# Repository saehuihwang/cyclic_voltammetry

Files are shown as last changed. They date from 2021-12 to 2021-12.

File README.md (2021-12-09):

# cyclic_voltammetry

Here, a functional cyclic voltametry (CV) device is presented. A three-electrode electrochemical cell is composed of a working electrode, a reference electrode, and a counter electrode. The working principle of cyclic voltammetry is that a range of voltages is applied to a working electrode and the resulting current is measured. This current can tell us information about an electrochemical redox reaction. Oxidation occurs at the working electrode, reduction occurs at the counter electrode.  

Following conventional CV design, a triangle wave is applied at the working electrode and current flowing between the working and counter electrode is measured. By plotting the current vs applied potential, a traditional "duck plot" can be obtained. 

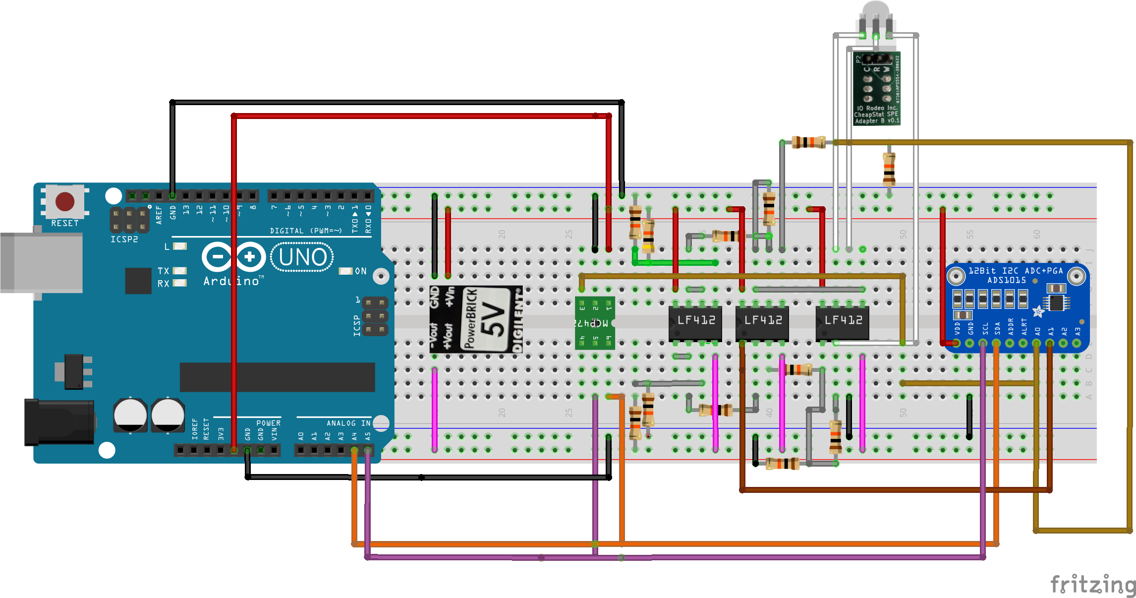
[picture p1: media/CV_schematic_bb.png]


### Duck plots
The Randles-Sevcik equation can be used to extract useful information about the electrochemical reaction. Detailed analysis can be found in the project report. 

Below are some examples of duck plots with varying parameters such as scan rate and concentration. 

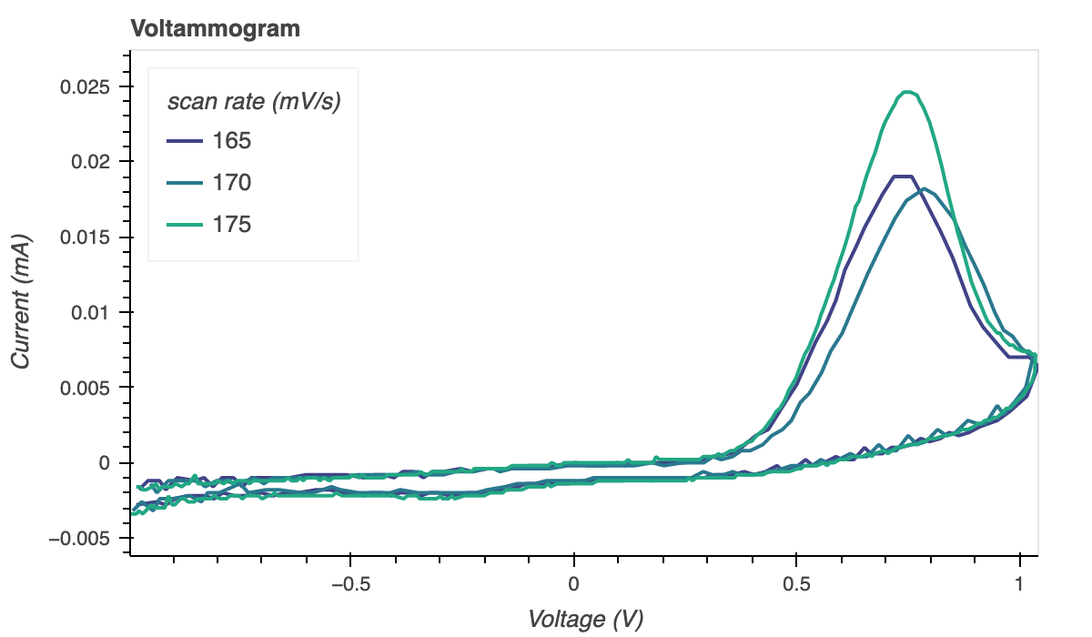
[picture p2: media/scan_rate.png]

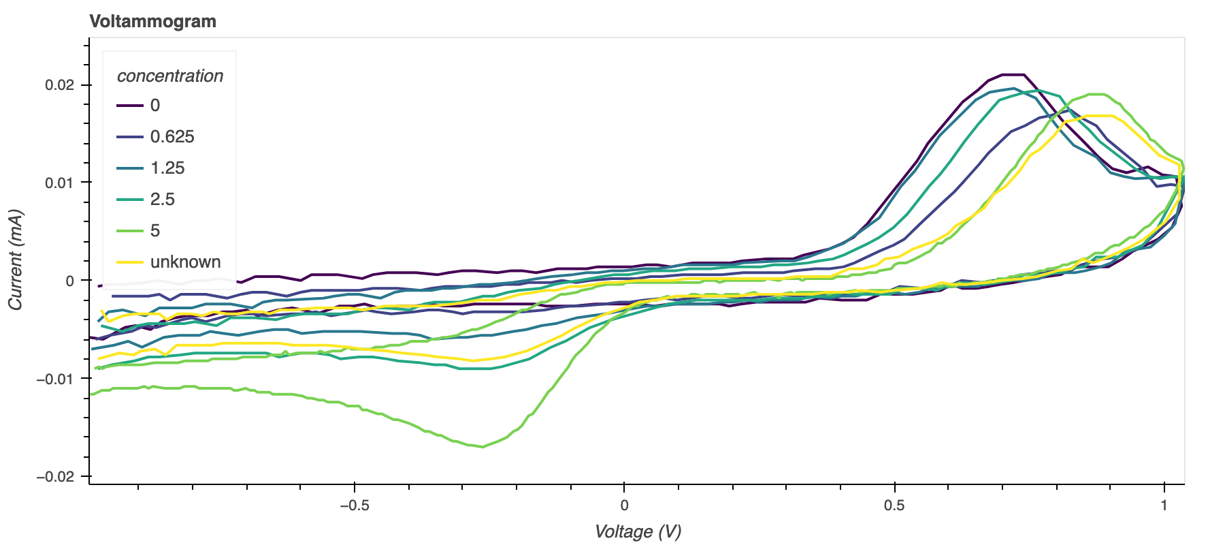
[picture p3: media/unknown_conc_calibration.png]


### App & User Interface 
To run the app, run 

  `bokeh serve --show cv_app.py`
  
On the command line.   
The following user interface will show, displaying the scan rate adjusting sliders and a plotting interface 
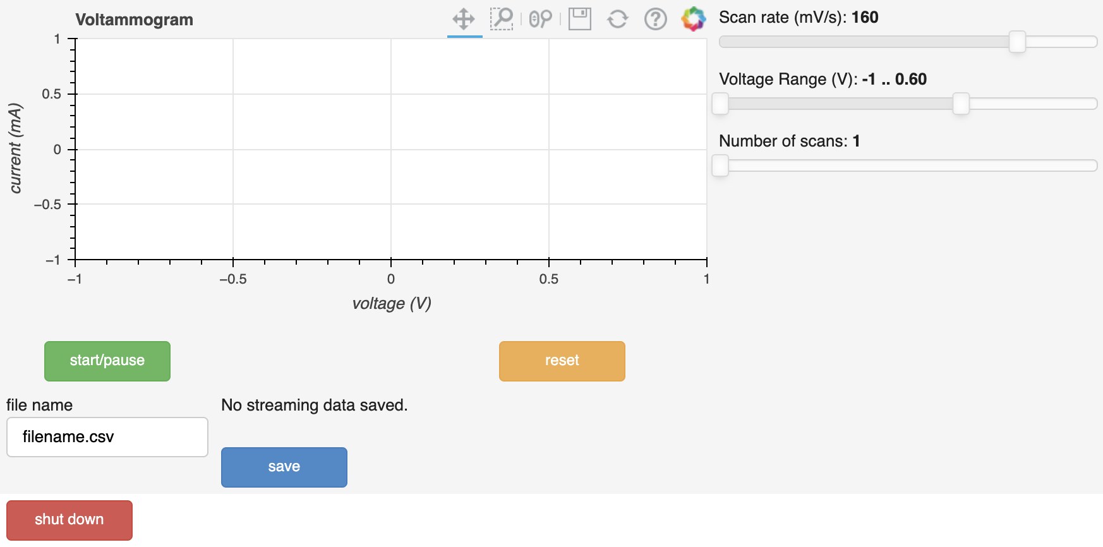
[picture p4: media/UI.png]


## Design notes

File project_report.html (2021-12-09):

## Section 1: Overview¶

In this report, a functional cyclic voltametry (CV) device is presented. A three-electrode electrochemical cell is composed of a working electrode, a reference electrode, and a counter electrode. The working principle of cyclic voltammetry is that a range of voltages is applied to a working electrode and the resulting current is measured. This current can tell us information about an electrochemical redox reaction. Oxidation occurs at the working electrode, reduction occurs at the counter electrode.

## Section 2: Design¶

Following conventional CV design, a triangle wave is applied at the working electrode and current flowing between the working and counter electrode is measured. By plotting the current vs applied potential, a traditional "duck plot" can be obtained.

The presented design is characterized by its easy-to-use user interface and its clean output trace. Significant attention has been paid to make the schematic and breadboard clean and easily readable. Furthermore, when saving the result to a .csv file, the scanning parameters (scan rate, scan range, # scan) are also saved to the file.

### Schematic¶

LF412 Dual Op-Amps were chosen for its low power requirement and high input impedance.

- Two reference voltages must be created at 1V and -2.5V. This is achieved using a simple resistive voltage divider and a buffer.
- Two subtractors are in place. All resistors in the subtractor is chosen to be the same value, $10k\Omega$. Therefore, the output of the subtractor is as follows: $$V_{out} = V_2 - V_1$$ where $V_2$ is the voltage connected to the positive terminal, and $V_1$ is the voltage connected to the negative terminal. When -2.5V is presented at $V_1$, this circuit behaves like an adder (+2.5V).
- The DAC can only output positive voltages ranging from 0Vto 5V. Therefore, we subtract 1V from the resulting signal in order to allow for a scanning range of -1V to 4V. Conventional CV applied potentials often lie within this range.
- The ADC can only read positive voltages, but we know that the measured TIA voltage could be negative. Therefore, the output of the TIA is shifted up by 2.5V. to provide for maximum reading range. Upon testing, this value has shown to be appropriate, as clipping was never observed. Upon reading the shifted output of the TIA, 2.5V is subtracted digitally to recover the original signal. The ADC's inability to read negative voltages also meant that the applied potential was measured before shifting it down by 1V. The signal was shifted down by 1V digitally to recover the actual applied potential value. In summary, the ADC was used to read two voltages: the DAC output and the TIA output.
- The current between the working and counter electrode is measured using a TIA. A simple resistive feedback op amp is used for this. A resistor value of $1k\Omega$ was specifically chosen for the feedback resistor, for a convenient conversion between measured volts to mA, according to $I = V/R$. Upon testing, no significant noise issues were present, so a capacitor has been omitted but it could be added at later design iterations if noise becomes an issue.

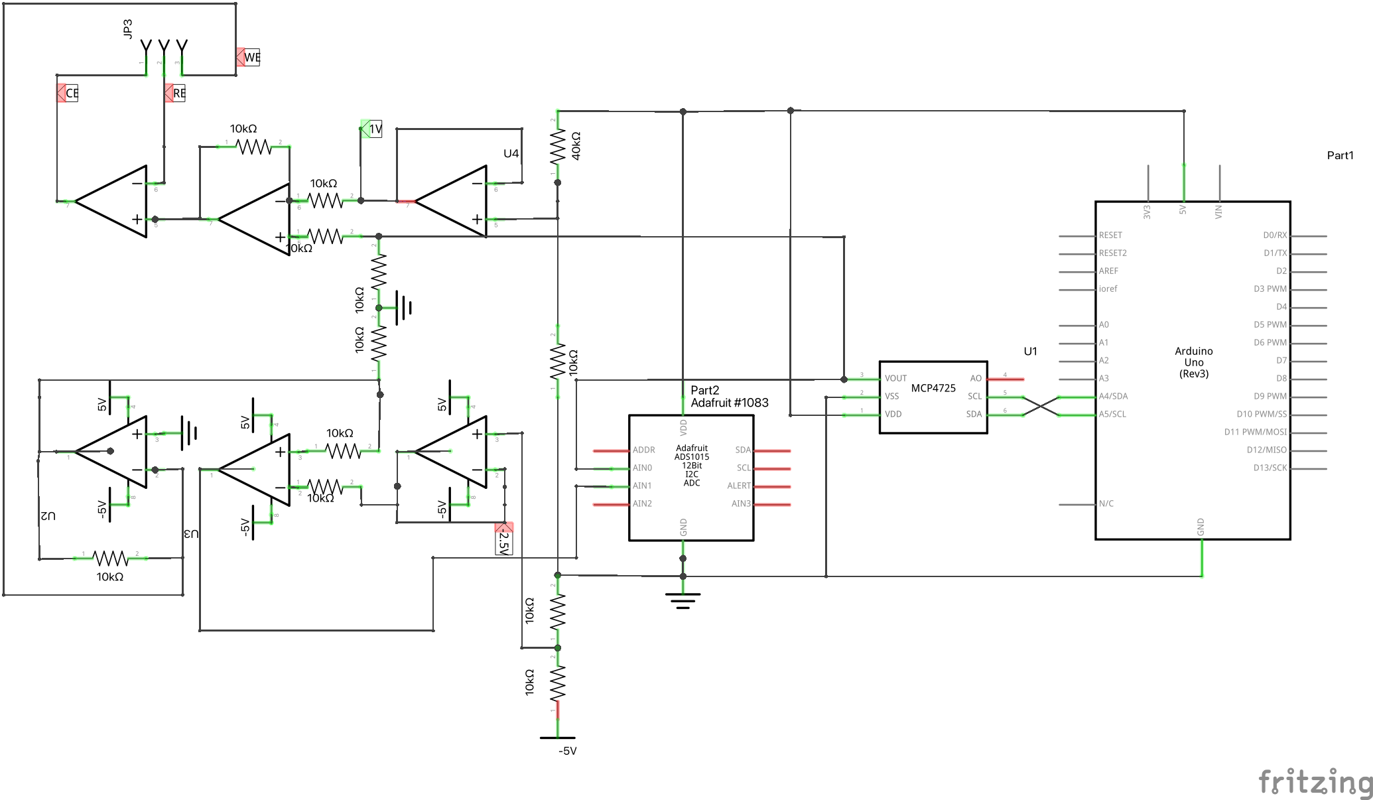
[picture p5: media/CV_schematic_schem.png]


### Breadboard Wiring¶



### Block Diagram¶

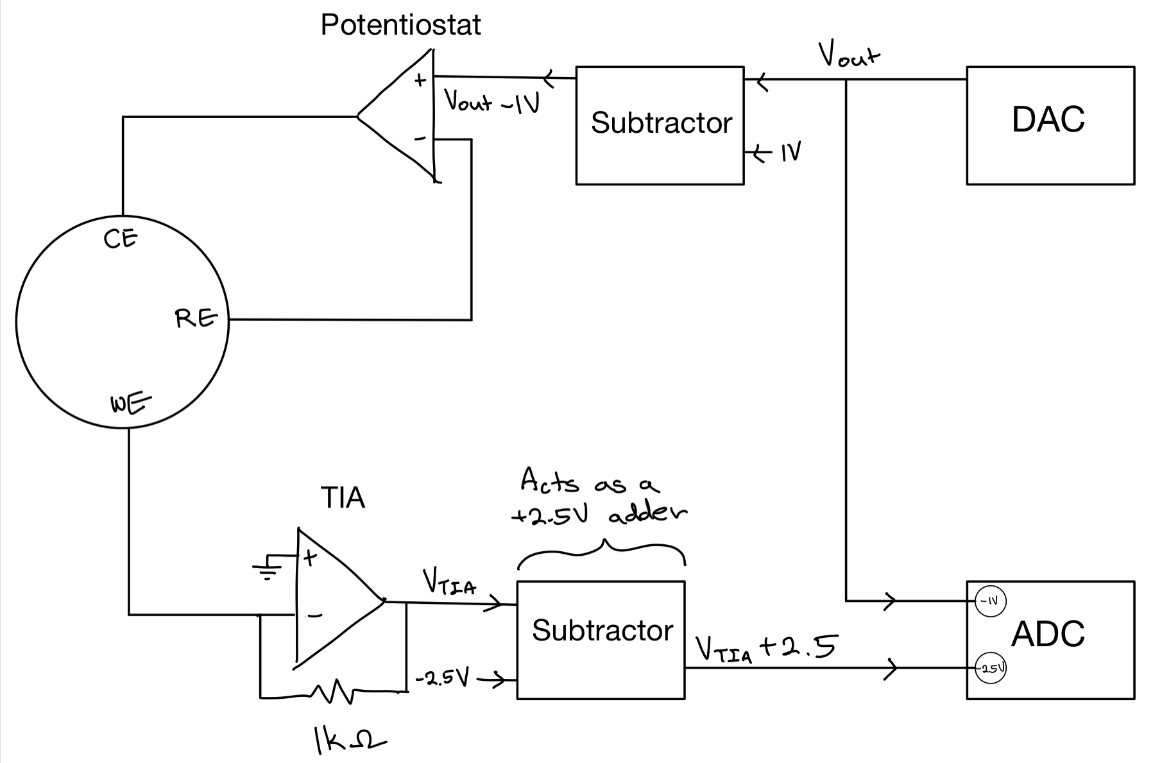
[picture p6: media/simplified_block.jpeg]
This simplified block diagram shows how signals were shifted up/down in analog and in digital domains. 

### User Interface¶

- The user interface has three sliders: a scanrate selector, a voltage range selector, and a scan number selector. A range slider is implemented for the voltage range slider so that the user is able to easily adjust the range using the two ends of the slider. The sliders are disabled during the course of a voltage scan. They are enabled once the voltage scanning is over or when it is reset.
- The start/pause button starts and pauses the voltage scan. When the user pauses the scan, the DAC holds the voltage. The user can press the button again to resume the scan.
- The reset button clears the plot and the data. The voltage scan is reset to 0V.
- The save button can be pressed while there is no active scanning. (i.e, can save when paused). The user is able to specify a file name. Any files with the same file name will be overwritten.
- The shut down button can be pressed to stop streaming and shut down the app.



### Software¶

#### Arduino¶

- There are several command bytes to control the arduino. Namely,
  - HANDSHAKE
  - START_PAUSE
  - STOP
  - READ_SWEEPTIME
  - READ_VLOW
  - READ_VHIGH
  - READ_NUM_SCAN
- The triangle wave generation is done ditigally . The main drawback of this approach is suboptimal voltage resolution. However, this method is much easier to debug and for prototyping purposes, it will suffice.
- The user is able to set the scan range anywhere from -1 to 4V. Since the DAC cannot output negative voltages, 1V is added to any user specified value and the corresponding DAC voltage is outputted, with the assumption that there is an op-amp subtractor that takes care of the subtraction in the analog domain.
- In other words, when the user specifies the desired voltage range as $V_{Low}$ and $V_{High}$, the DAC translation for a desired voltages is computed as follows $$dac_{vLow} = \frac{V_{Low} + 1}{5} \cdot 4095 $$ $$dac_{vHigh} = \frac{V_{High} + 1}{5} \cdot 4095 $$ One downside of this method is that the voltage resolution is limited by 1.2mV. Even when the desired amplitude is smaller, the voltage resolution stays the same. We are not taking full advantage of the 12 bit DAC when the desired amplitude is less than 5V.
- The MCP4725 $V_{out}$ ranges from $V_{SS}$ (0V) to $V_{DD}$ (5V). There is a counter that counts up (for rising edge) or down (for falling edge) from the bit translation of $V_{low}$ (for rising edge) or $V_{high}$ (for falling edge).
- The scan rate is implemented as follows
  - For convenience and readability, "sweeptime" is used in the arduino code rather than the conventional "scan rate". The sweeptime is another word for "period" of the triangle wave. The conversion is quite simple $${sweeptime} = (({V_{high} - V_{low}}) \div {scanrate}) \times 2 $$ and is done on the python side
  - There is a .delay() of $\frac{sweeptime}{2} \div \text{bit translation of amplitude}$ in between DAC outputs. This is because the bit translation of amplitude represents the number of discrete voltage values that needs to be outputted during the rising/falling edge. This method relies upon the assumption that the ADC reading and DAC outputting operation takes negligible time. Therefore the actual sweeptime may be slightly more than the user specified value. This also has the downside that the sweeprate is limited by the arduino baud rate. The minimum sweep rate was measured to be around 10 seconds. Luckily for us, conventional sweeptimes are longer than this. The last drawback is the reduced time resolution. Since the arduino is under delay(), the ADC is unable to read anything during this time. This results in a reduced number of data points.
- After each voltage output, the code checks if there were any START_PAUSE command or STOP command. This allows us to hold or reset the voltage during a sweep.
- When the sweep is complete, the message "DONE SWEEPING" is outputted to serial so that the python side can immediately know when the sweeping has concluded.
- When no sweeping is taking place, the DAC outputs the voltage of 1V which is shifted down to 0V by the subtractor (OFF state). #### Python
- Since the 1V subtractor and the 2.5V adder is implemented in analog to output the correct voltage, we must subtract 1V and subtract 2.5V digitally to compensate (see block diagram).
- When saving to a .csv file, the user specified scanning parameters are saved at the top of the csv file so that when doing analysis, the user can easily recover the scan parameters that were used.

## Section 3: Instructions for Use¶

1. Rinse the DropSens SPCE under running water and let it air dry before plugging into the adaptor.
2. Use a clean pipette to drop 1 or 2 drops of analyte to the DropSense SPCE such that the three electrodes are fully covered. This should be approximately 50$\mu L$ of analyte. Be careful not to touch the electrode surface with the pipette tip.
3. Make the sure electrode is flat against the table.
4. Run the app from the terminal bokeh serve --show cv_app.py
5. Adjust scanning parameters by dragging the sliders
  - scan rate (mV/s)
  - voltage range (V)
  - number of scans
6. Click start/pause
7. To pause during a scan, click start/pause. To stop the scan, click reset. During a scan, the scanning parameters cannot be adjusted
8. To save a trace, specify a file name and click save. One can save when the scanning is paused or when the scanning has been completed.
9. When finished, gently rinse under running water and let it air dry before storing away from direct sunlight. The app can be closed by clicking shut down.

## Section 4: Demonstration and assessment¶

#### Voltage Scan verification¶

An oscilloscope was used to verify that the triangle wave output was as expected. 
Channel 1 is the DAC output and Channel 2 is the subtractor output. A shift of 1V is measured, as expected. A sweeptime of 1.4 seconds was specified to the arduino and the measured period is 1.48 seconds, as expected. No distortions are observed.

#### Demonstration video.¶

A video footage of the functioning device is included in the media/ folder.

## Section 5: Analysis of data¶

In [1]:

import pandas as pd
import scipy.signal
import numpy as np
import os
import holoviews as hv
import bokeh.plotting
import bokeh.io

bokeh.io.output_notebook()
hv.extension("bokeh")
%load_ext blackcellmagic

(https://bokeh.org) Loading BokehJS ...

#### Helper Functions¶

In [7]:

def tidy_cv_df(filename, conc=None):
    """ turns a raw .csv file name into a tidy dataframe """
    df = pd.read_csv(filename)
    df["scan rate (mV/s)"] = int(df["0"][0])
    df["scan low (V)"] = df["0"][1]
    df["scan high (V)"] = df["0"][2]
    df["num scan"] = df["0"][3]
    df["Voltage (V)"] = df["Voltage (V)"] - 1
    df["Current (mA)"] = (df["Current (mA)"] - 2.5)/10
    if conc is not None:
        df["concentration"] = conc
    return df[4:].reset_index(drop=True)

def cap_curr_fit(df, v_oxidation):
    """returns the line of best fit for the capacitive current"""
    x_range = df["Voltage (V)"]
    data = df.loc[df["Voltage (V)"] < v_oxidation]
    mid_time = np.median(df["time (ms)"])
    x = data.loc[data["time (ms)"] < mid_time]["Voltage (V)"]
    y = data.loc[data["time (ms)"] < mid_time]["Current (mA)"]
    line_fit = np.poly1d(np.polyfit(x, y, 1))

    return x_range, line_fit(x_range)

def extract_ipa(df, v_oxidation=0.2):
    """ calculates the peak anodic current by maximizing the distance 
    between the capacitive current and the measured current """
    y = df["Current (mA)"]
    y_line = cap_curr_fit(df, v_oxidation)[1]

    ind_max = np.argmax((y - y_line) ** 2)
    # peak anodic current
    ipa = y[ind_max] - y_line[ind_max]
    return (ind_max, ipa)

Now that we have some helper functions, let's look at some duck plots!

#### Effects of the number of scans¶

We observe that the peak anodic potential decreases to a negligible amount after the first scan. This makes sense because we know that the reaction of Ascorbic acid is irreversible (further discussion below). After the first scan the surface of the electrode is oxidized and no further oxidation occurs. This is why from now on, we will simply conduct $n=1$ scans.

#### Effect of scan rate on $i_{pa}$¶

In [8]:

data_path = './data/diffusion_coeff_data/'
rates = [175, 170, 165]
dfs = [tidy_cv_df(os.path.join(data_path, f"0.625mM_{rate}.csv")) for rate in rates]

df = pd.concat(dfs)

p = (
    hv.Curve(data=df, kdims="Voltage (V)", vdims=["Current (mA)", "scan rate (mV/s)"])
    .groupby("scan rate (mV/s)")
    .opts(
        color=hv.Cycle(list(bokeh.palettes.Viridis6[1:-1])),
        width=600,
        height=350,
        title="Voltammogram",
    )
    .overlay().opts(legend_position='top_left')
)

p = hv.render(p)
bokeh.io.show(p)

We observe that there is negligible cathodic peak current. This allows us to deduce that the reaction of vitamin C is irreversible. This is in line with our understanding of vitamin C as an antioxidant, as it is a reducing agent.

Visually, we can see that as scan rate increases, so does the peak anodic current ($i_{pa}$). We have written up a helper function to extract this value. To demonstrate that the extraction of $i_{pa}$ works as expected, we will visualize one of the curves.

In [9]:

df_170 = df.loc[df["scan rate (mV/s)"] == 170]

p = hv.render(
    hv.Curve(data=df_170, kdims="Voltage (V)", vdims=["Current (mA)"]).opts(
        width=600,
        height=350,
        title="Voltammogram",
    )
)

ipa_ind, ipa = extract_ipa(df_170)
cap_curr_x, cap_curr_y = cap_curr_fit(df_170, 0.2)

# Plot
p.line(x=cap_curr_x, y=cap_curr_y, line_dash='dashed', color='black', width=3)
p.circle(
    x=df_170["Voltage (V)"][ipa_ind], y=df_170["Current (mA)"][ipa_ind], color="red", size=5
)
p.segment(
    x0=cap_curr_x[ipa_ind],
    y0=cap_curr_y[ipa_ind],
    x1=df_170["Voltage (V)"][ipa_ind],
    y1=df_170["Current (mA)"][ipa_ind],
    color="pink", width=5
)
bokeh.plotting.show(p)

The pink line segment represents the calculated $i_{pa}$. $i_{pa}$ is found by maximizing the distance between the capacitive current and the trace. Accurately finding the capacitive current requires a careful consideration of the theory and doing generative modeling. For simplicity, we have simply done a linear fit of the region below 0.2V, as that is where the plot seems to behave linearly. Now that we've verified our helper functions, we can use this to calculate the diffusion coefficient.

#### Extracting the diffusion coefficient¶

Multiple CV experiments for various scan rates have been performed. Then, a least squares regression of $i_{pa}$ vs $v$ according to the Randles-Sevcik equation, $$i_{pa} = 0.4463nFAc\sqrt{\frac{nFvD}{RT}}$$ was performed.

parameter | Description | Value
n | number of electrons transferred | $$1$$
A | electrode area | $$\pi \cdot (0.2)^2 (cm^2)$$
T | temperature | $$293 (K)$$
v | scan rate | varies $(V/s)$
F | Faraday Constant | $$96500 (C/mol)$$
D | Diffusion Coefficient | want to find $ (cm^2/s)$
R | Gas Constant | $$8.31 (J/(K mol))$$
C | concentration | $$6.25 \cdot 10^{-7} (mol/cm^3)$$

We will let $n=1$, as suggested $\href{https://en.wikipedia.org/wiki/Randles%E2%80%93Sevcik_equation}{here} $

In [10]:

# create a dataframe of peak anodic current wrt. scan rate
dfs = []
for rate in df["scan rate (mV/s)"].unique():
    ipa_ind, ipa = extract_ipa(df.loc[df["scan rate (mV/s)"] == rate])
    dfs.append(pd.DataFrame({"scan rate (mV/s)": rate, "ipa (mA)": ipa}, index=[0]))
ipas = pd.concat(dfs).reset_index(drop=True)
ipas["scan rate (V/s)"] = ipas["scan rate (mV/s)"] / 1000
ipas["ipa (A)"] = ipas["ipa (mA)"] / 1000

def randles(v, D):
    """ The Randles-Sevcik equation used in `scipy.optimize.curve_fit` """
    n = 1
    r = 0.2  # cm
    A = np.pi * r ** 2 # cm^2
    R = 8.31 # J/(K mol)
    F = 96500 # in C / mol
    T = 293  # room temperature
    c = 0.625 / 1000 * 1000 / (100 ** 3) # mol / cm^3
    return (
        0.4463 * n * F * A * c * (n * F * v * D / (R * T)) ** (1 / 2)
    )

popt, pcov = scipy.optimize.curve_fit(randles, ipas["scan rate (V/s)"], ipas["ipa (A)"])

# plot
p = bokeh.plotting.figure(
    width=400,
    height=400,
    x_axis_label="scan rate (mV/s)",
    y_axis_label="peak anodic current (mA)",
)
p.circle(x=ipas["scan rate (mV/s)"], y=ipas["ipa (mA)"])
v_range = np.linspace(0.1, 0.2, 1000)
p.line(x=1000*v_range, y=randles(v_range, *popt)*1000)
bokeh.io.show(p)

In [11]:

print(f"Calculated Diffusion Coefficient in cm^2/s: {popt}")

Calculated Diffusion Coefficient in cm^2/s: [5.06907637e-06]

Literature ($\href{https://pubs.rsc.org/en/content/articlelanding/2020/NJ/D0NJ02175J}{Yomthiangthae, 2020}$) suggests that the diffusiuon coefficient of vitamin C is $5.32 \cdot 10^{-6} {cm}^2 s^{-1}$. Our estimated value for the diffusion coefficient is similar to this value by an order of magnitude!

One important thing to note is that the measured current has been divided by 10 in tidy_cv_df() because our measured current using the arduino was off by a factor of 10 from the measured current using a multimeter. It is unclear why this happened, but this behavior has also been observed by other students. After intensive debugging, the source of this 10x factor was not found. It may be that the SPCE has an internal resistance that we neglected to account for. For analytical purposes, we divide the arduino current readout by 10 so that it matches the current readout from the multimeter.

Furthermore, of course, ideally, we would have more datapoints to help us be more confident in our diffusion coefficient fit. Due to time constraints, only three data points have been acquired.

### Calculating an unknown concentration¶

Since we have found that our diffusion coefficient calculation is likely flawed, we can use a more direct approach in calculating the concentration of an unknown solution.

In [12]:

data_path = './data/calibration_data/'

concentrations = [0, 0.625, 1.25, 2.5, 5, 'unknown']
dfs = [tidy_cv_df(os.path.join(data_path, f"calibrate_{conc}mM.csv"), conc) for conc in concentrations]

df = pd.concat(dfs)

p = (
    hv.Curve(data=df, kdims="Voltage (V)", vdims=["Current (mA)", "concentration"])
    .groupby("concentration")
    .opts(
        color=hv.Cycle(list(bokeh.palettes.Viridis6)),
        width=900,
        height=400,
        title="Voltammogram",
    )
    .overlay().opts(legend_position='top_left')
)

p = hv.render(p)
bokeh.io.show(p)

We again extract $i_{pa}$ and store it in a dataframe.

In [13]:

dfs=[]
for conc in df["concentration"].unique():
    ipa_ind, ipa = extract_ipa(df.loc[df["concentration"]==conc], v_oxidation=-0.5)
    dfs.append(pd.DataFrame({"concentration":conc, "ipa": ipa}, index=[0]))
    
ipas = pd.concat(dfs).reset_index(drop=True)
ipas

Out[13]:

| concentration | ipa
0 | 0 | 0.017524
1 | 0.625 | 0.016405
2 | 1.25 | 0.015526
3 | 2.5 | 0.018170
4 | 5 | 0.020856
5 | unknown | 0.017032

From the Randles-Sevcik equation, $$i_{pa} = 0.4463nFAc\sqrt{\frac{nFvD}{RT}}$$ we know that $i_{pa}$ has a linear relationship with $c$, the concentration. We will conduct a linear fit of our data to find the unknown concentration.

In [14]:

known_conc = ipas.loc[ipas["concentration"] != "unknown"].astype("float")
p = bokeh.plotting.figure(width = 400, height=400, x_axis_label="concentration", y_axis_label="peak anodic current (mA)")
p.circle(x=known_conc["concentration"], y=known_conc["ipa"])
z = np.polyfit(known_conc["concentration"], known_conc["ipa"], 1)
best_fit_line = np.poly1d(z)
conc_range = np.linspace(0,5,100)
p.line(x=conc_range, y=best_fit_line(conc_range), line_dash='dashed', color='black')

unknown_ipa = ipas.loc[ipas["concentration"] == 'unknown']['ipa'].values
unknown_conc = ( unknown_ipa - z[1])/z[0]
p.circle(x=unknown_conc, y=unknown_ipa, color='red')
bokeh.io.show(p)

In [15]:

print(f"The unknown concentration is approximately: {unknown_conc} mM")

The unknown concentration is approximately: [1.10359977] mM

## Section 6: Suggestions for the next design phase¶

1. Understand the behavior of the screen printed carbon electrode better
  - We still don't quite understand why the arduino read of the current is higher than that from a multimeter by an order of magnitude. Other members of the class also reported this behavior. We should test this by using a non-drop-based electrode (i.e. standard electrochemical cell).
2. Voltage resolution
  - Currently, when the voltage range of the desired scan is smaller than 5V pp, we do not take advantage of the full 12 bits, as explained in the design section. This leads to a sub-optimal voltage resolution. Instead of doing the voltage scan digitally, we can conduct it in analog domain. For example, we can control the gain of an op amp to make sure we are taking full advantage of the DAC bit range.
3. Temporal resolution
  - We have implemented the scan rate variation by chaning the delay() duration. delay() of the arduino is a "blocking" operation. This means that we are unable to read any TIA outputs (i.e. measure current) for the duration of the delay(). This results in a sub-optimal temporal resolution. To overcome this, an exact function that returns the desired voltage at a specified time can be created. This function would have the call signature triangle(time, V_max, V_min). This way, the temporal resolution of the sweep is limited only by the baud rate, and the ADC voltage reads can be done as fast as possible.
4. User Interface
  - There's always improvements to make in the user interface. We could embed $i_{pa}$ and $i_{pc}$ calculation features to the app should the user want to use it. We could also make the status of the scan more clear by outputting text such as "INCOMPLETE" and "COMPLETE" depending on the scanning status.

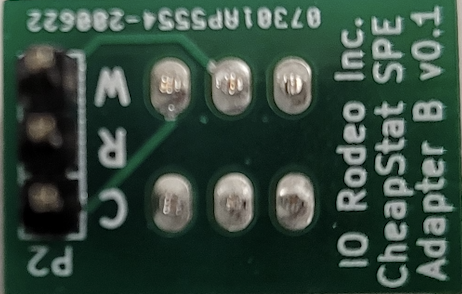
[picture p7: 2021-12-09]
media/adaptor.png

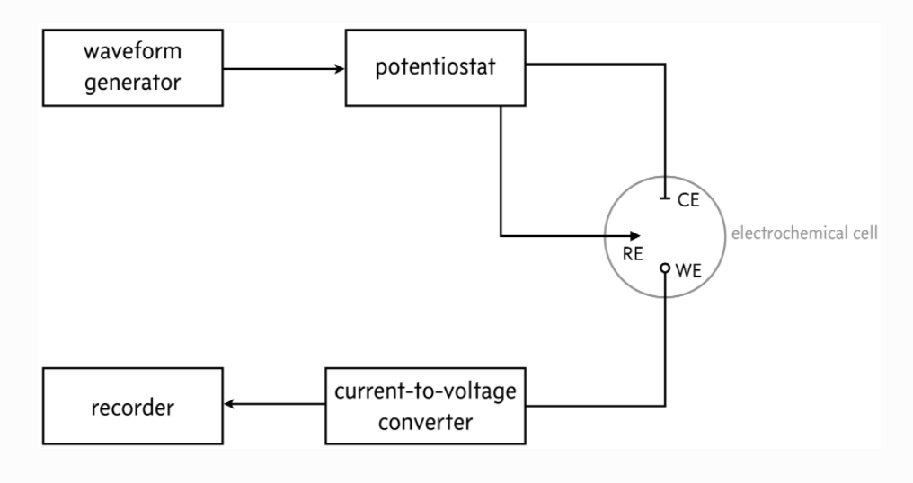
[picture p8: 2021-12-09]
media/block_diagram.png

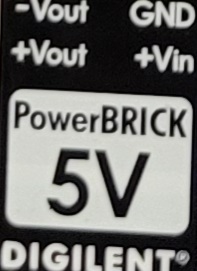
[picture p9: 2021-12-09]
media/powerbrick.jpeg

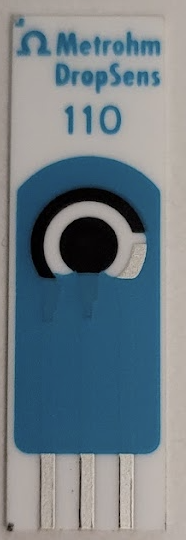
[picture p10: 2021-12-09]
media/electrode.png

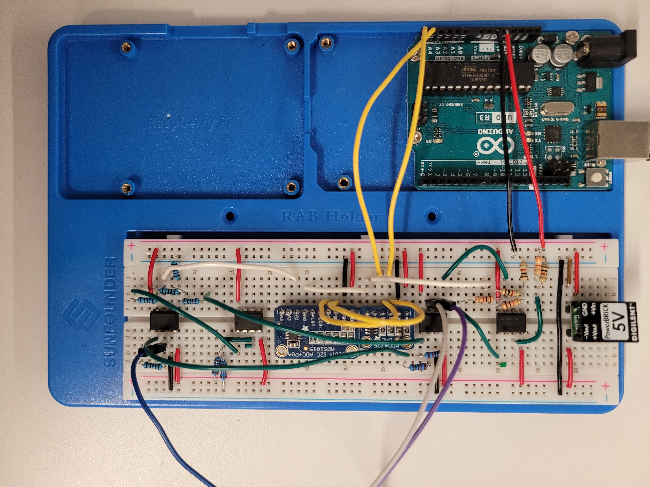
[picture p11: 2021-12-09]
media/breadboard.jpeg

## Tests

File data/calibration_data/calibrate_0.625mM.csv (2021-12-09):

index | 0 | time (ms) | Voltage (V) | Current (mA)
scanrate (mV/s) | 160.0
scan low (V) | -1.0
scan high (V) | 1.0
num scan | 1.0
 |  | 1381891.0 | 0.05 | 2.484
 |  | 1382282.0 | 0.09 | 2.484
 |  | 1382539.0 | 0.118 | 2.484
 |  | 131382734.0 | 0.138 | 2.486
 |  | 1382930.0 | 0.158 | 2.48
 |  | 1383126.0 | 0.178 | 2.486
 |  | 1383382.0 | 0.204 | 2.486
 |  | 131383578.0 | 0.224 | 2.486
 |  | 1383969.0 | 0.264 | 2.482
 |  | 1384226.0 | 0.29 | 2.486
 |  | 1384422.0 | 0.31 | 2.488
 |  | 1384679.0 | 0.336 | 2.488
 |  | 1385071.0 | 0.374 | 2.484
 |  | 1385328.0 | 0.4 | 2.488
 |  | 1385524.0 | 0.42 | 2.49
 |  | 1385720.0 | 0.442 | 2.49
 |  | 13851385977.0 | 0.468 | 2.49
 |  | 1386369.0 | 0.508 | 2.49
 |  | 1386626.0 | 0.534 | 2.492
 |  | 1386821.0 | 0.554 | 2.492
 |  | 11387078.0 | 0.58 | 2.492
 |  | 1387470.0 | 0.622 | 2.49
 |  | 1387666.0 | 0.642 | 2.492
 |  | 1387923.0 | 0.668 | 2.494
 |  | 1388180.0 | 0.694 | 2.494
 |  | 1388311388377.0 | 0.712 | 2.494
 |  | 1388768.0 | 0.752 | 2.494
 |  | 1389025.0 | 0.778 | 2.496
 |  | 1389282.0 | 0.804 | 2.496
 |  | 1381389477.0 | 0.824 | 2.498
 |  | 1389870.0 | 0.864 | 2.498
 |  | 1390065.0 | 0.884 | 2.5
 |  | 1390322.0 | 0.91 | 2.498
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

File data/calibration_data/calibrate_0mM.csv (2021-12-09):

index | 0 | time (ms) | Voltage (V) | Current (mA)
scanrate (mV/s) | 160.0
scan low (V) | -1.0
scan high (V) | 1.0
num scan | 1.0
 |  | 1949798.0 | 0.024 | 2.494
 |  | 1949993.0 | 0.044 | 2.496
 |  | 195011950251.0 | 0.07 | 2.496
 |  | 1950641.0 | 0.112 | 2.498
 |  | 1950898.0 | 0.138 | 2.5
 |  | 1951289.0 | 0.178 | 2.496
 |  | 1951546.0 | 0.204 | 2.5
 |  | 1951741.0 | 0.224 | 2.5
 |  | 1951931951998.0 | 0.25 | 2.502
 |  | 1952390.0 | 0.29 | 2.498
 |  | 1952647.0 | 0.316 | 2.504
 |  | 1952904.0 | 0.342 | 2.504
 |  | 1951953100.0 | 0.36 | 2.504
 |  | 1953491.0 | 0.4 | 2.5
 |  | 1953687.0 | 0.42 | 2.506
 |  | 1953944.0 | 0.448 | 2.506
 |  | 1954141.0 | 0.468 | 2.506
 |  | 1954593.0 | 0.514 | 2.502
 |  | 1954789.0 | 0.534 | 2.506
 |  | 1955046.0 | 0.56 | 2.508
 |  | 1955303.0 | 0.586 | 2.508
 |  | 1.9551955500195555e+17 | 0.614 | 2.508
 |  | 1955952.0 | 0.654 | 2.506
 |  | 1956148.0 | 0.674 | 2.508
 |  | 1956405.0 | 0.7 | 2.51
 |  | 11951956662.0 | 0.724 | 2.51
 |  | 1957054.0 | 0.764 | 2.508
 |  | 1957311.0 | 0.79 | 2.51
 |  | 1957507.0 | 0.81 | 2.51
 |  | 1957764.0 | 0.836 | 2.508
 |  | 1958156.0 | 0.876 | 2.512
 |  | 1958413.0 | 0.902 | 2.512
 |  | 1958670.0 | 0.93 | 2.512
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

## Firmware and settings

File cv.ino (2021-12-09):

#include <Wire.h>
#include <Math.h>
#include <Adafruit_MCP4725.h>
#include <Adafruit_ADS1X15.h>
Adafruit_ADS1015 ads;

//This is the I2C Address of the MCP4725, by default (A0 pulled to GND).
//For devices with A0 pulled HIGH, use 0x63
#define MCP4725_ADDR 0x62

const int HANDSHAKE = 0;
const int START_PAUSE = 4; 
const int READ_SWEEPTIME = 5;
const int READ_VLOW = 6;
const int READ_VHIGH = 7;
const int READ_NUM_SCAN = 8;
const int STOP = 9;
const int vSweepPin = A1;

// Default values
bool continue_scan;
float sweeptime = 20; //seconds
float vLow = -1;
float vHigh = 0.6; 
int numScan = 1; 
float vLow_comp = vLow + 1;
float vHigh_comp = vHigh + 1;

// Instantiate the DAC
Adafruit_MCP4725 dac;

void setup() {
  dac.begin(MCP4725_ADDR);
  ads.setGain(GAIN_ONE);
  ads.begin();
  Serial.begin(115200);
  vLow_comp = vLow + 1;
  vHigh_comp = vHigh + 1;
  Serial.println();
}

bool check_start_pause_cmd() {
  // Check if data has been sent to Arduino and respond accordingly
  if (Serial.available() > 0) {
    // Read in request
    int inByte = Serial.read();
    if (inByte == START_PAUSE) {
      continue_scan = !continue_scan;
    }
    if (inByte == STOP) {
      return false;
    }
    return true;
  }
  return true;
}

void sweep_voltage() {
  for (int scan_i = 1 ; scan_i <= numScan ; scan_i++) {
    // Run through the full 12-bit scale for a triangle wave
    uint32_t dac_vLow = uint32_t(round(vLow_comp / 5.0 * 4095.0));
    uint32_t dac_vHigh = uint32_t(round(vHigh_comp / 5.0 * 4095.0));
    for (uint32_t counter_up = dac_vLow; counter_up <  dac_vHigh; counter_up++)
    {
      
      if (continue_scan) {
        dac.setVoltage(counter_up, false);
        delay(sweeptime / 2 / (dac_vHigh - dac_vLow) * 1000);
        int16_t v_Sweep = ads.readADC_SingleEnded(0);
        int16_t v_TIA = ads.readADC_SingleEnded(1);
        unsigned long timeMilliseconds = millis();
        Serial.println(String(String(timeMilliseconds,DEC)+ "," + String(v_Sweep, DEC)+ "," + String(v_TIA, DEC)));
        if (check_start_pause_cmd() == false) {
          dac.setVoltage(uint32_t(819), false);
          return;
        }
      }
      else {
        while (continue_scan == false) {
          if (check_start_pause_cmd() == false) {
            dac.setVoltage(uint32_t(819), false);
            return;
          }
        }
      }
      
    }
 
    for (uint32_t counter_dn = dac_vHigh; counter_dn > dac_vLow; counter_dn--)
    {
      if (continue_scan) {
        dac.setVoltage(counter_dn, false);
        delay(sweeptime / 2 / (dac_vHigh - dac_vLow) * 1000);
        int16_t v_Sweep = ads.readADC_SingleEnded(0);
        int16_t v_TIA = ads.readADC_SingleEnded(1);
        unsigned long timeMilliseconds = millis();
        Serial.println(String(String(timeMilliseconds,DEC)+ "," + String(v_Sweep, DEC) + "," + String(v_TIA, DEC)));
        if (check_start_pause_cmd() == false) {
          dac.setVoltage(uint32_t(819), false);
          return;
        }
      }
      else {
        while (continue_scan == false) {
          if (check_start_pause_cmd() == false) {
            dac.setVoltage(uint32_t(819), false);
            return;
          }
        }
      }
    }
  }
  dac.setVoltage(uint32_t(819), false);
  Serial.println("DONE SWEEPING");
  Serial.println("DONE SWEEPING");
  Serial.println("DONE SWEEPING");
  Serial.println("DONE SWEEPING");
  Serial.println("DONE SWEEPING");
}

void loop() {
  // Check if data has been sent to Arduino and respond accordingly
  if (Serial.available() > 0) {
    // Read in request
    int inByte = Serial.read();
    // If data is requested, fetch it and write it, or handshake
    switch(inByte) {
      case START_PAUSE:
        continue_scan = true;
        sweep_voltage();
        break;
      case READ_SWEEPTIME:
        // Read in frequency
        sweeptime = Serial.readStringUntil('x').toFloat();
        break;
      case READ_VLOW:
        vLow = Serial.readStringUntil('x').toFloat();
        vLow_comp = vLow + 1;
        break;
      case READ_VHIGH:
        vHigh = Serial.readStringUntil('x').toFloat();
        vHigh_comp = vHigh + 1;
        break;
      case READ_NUM_SCAN:
        numScan = Serial.readStringUntil('x').toInt();
        break;
      case HANDSHAKE:
        if (Serial.availableForWrite()) {
          Serial.println("Message received.");
        }
        break;
    }
  }
}

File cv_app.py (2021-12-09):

"""
Cyclic Voltammetry App

To serve the app, run

    bokeh serve --show cv_app.py

on the command line.
"""

import asyncio
import re
import time

import pandas as pd
import numpy as np

import serial
import serial.tools.list_ports

import bokeh.plotting
import bokeh.io
import bokeh.layouts
import bokeh.driving

bokeh.io.output_notebook()

notebook_url = "localhost:8888"

def find_arduino(port=None):
    """Get the name of the port that is connected to Arduino."""
    if port is None:
        ports = serial.tools.list_ports.comports()
        for p in ports:
            if p.manufacturer is not None and "Arduino" in p.manufacturer:
                port = p.device
    return port


def handshake_arduino(
    arduino, sleep_time=1, print_handshake_message=False, handshake_code=0
):
    """Make sure connection is established by sending
    and receiving bytes."""
    # Close and reopen
    arduino.close()
    arduino.open()

    # Chill out while everything gets set
    time.sleep(sleep_time)

    # Set a long timeout to complete handshake
    timeout = arduino.timeout
    arduino.timeout = 2

    # Read and discard everything that may be in the input buffer
    _ = arduino.read_all()

    # Send request to Arduino
    arduino.write(bytes([handshake_code]))

    # Read in what Arduino sent
    handshake_message = arduino.read_until()

    # Send and receive request again
    arduino.write(bytes([handshake_code]))
    handshake_message = arduino.read_until()

    # Print the handshake message, if desired
    if print_handshake_message:
        print("Handshake message: " + handshake_message.decode())

    # Reset the timeout
    arduino.timeout = timeout


def read_all(ser, read_buffer=b"", **args):
    """Read all available bytes from the serial port
    and append to the read buffer.

    Parameters
    ----------
    ser : serial.Serial() instance
        The device we are reading from.
    read_buffer : bytes, default b''
        Previous read buffer that is appended to.

    Returns
    -------
    output : bytes
        Bytes object that contains read_buffer + read.

    Notes
    -----
    .. `**args` appears, but is never used. This is for
       compatibility with `read_all_newlines()` as a
       drop-in replacement for this function.
    """
    # Set timeout to None to make sure we read all bytes
    previous_timeout = ser.timeout
    ser.timeout = None

    in_waiting = ser.in_waiting
    read = ser.read(size=in_waiting)

    # Reset to previous timeout
    ser.timeout = previous_timeout

    return read_buffer + read


def read_all_newlines(ser, read_buffer=b"", n_reads=4):
    """Read data in until encountering newlines.

    Parameters
    ----------
    ser : serial.Serial() instance
        The device we are reading from.
    n_reads : int
        The number of reads up to newlines
    read_buffer : bytes, default b''
        Previous read buffer that is appended to.

    Returns
    -------
    output : bytes
        Bytes object that contains read_buffer + read.

    Notes
    -----
    .. This is a drop-in replacement for read_all().
    """
    raw = read_buffer
    for _ in range(n_reads):
        raw += ser.read_until()
    return raw


def parse_read2(read):
    """Parse a read with time, and two volage data

    Parameters
    ----------
    read : byte string
        Byte string with comma delimited time/voltage
        measurements.

    Returns
    -------
    time_ms : list of ints
        Time points in milliseconds.
    voltage1 : list of floats
        Voltages in volts.
    voltage2 : list of floats
        Voltages in volts
    remaining_bytes : byte string
        Remaining, unparsed bytes.
    """
    time_ms = []
    voltage1 = []
    voltage2 = []
    temp = []

    # Separate independent time/voltage measurements
    pattern = re.compile(b"\d+|,")
    raw_list = [b"".join(pattern.findall(raw)).decode() for raw in read.split(b"\r\n")]

    for raw in raw_list[:-1]:
        try:
            t, V1, V2 = raw.split(",")
            time_ms.append(int(t))
            voltage1.append(int(V1) * 2 / 1000)  # gain 1 : 1bit = 2mV
            voltage2.append(int(V2) * 2 / 1000)  # gain 1 : 1bit = 2mV

        except:
            pass
    if len(raw_list) == 0:
        return time_ms, voltage1, voltage2, b""
    else:
        return time_ms, voltage1, voltage2, raw_list[-1].encode()


async def daq_stream_async2_cv(
    arduino, data, delay=20, n_trash_reads=5, n_reads_per_chunk=4, reader=read_all
):
    # Receive data
    read_buffer = [b""]

    while True:
        if data["curr_streaming"] == True:
            # Read and throw out first few reads
            i = 0
            while i < n_trash_reads:
                _ = arduino.read_until()
                i += 1

            # Read in chunk of data
            raw = reader(arduino, read_buffer=read_buffer[0], n_reads=n_reads_per_chunk)
            # check if done sweeping
            if b"DONE" in raw:
                data["curr_streaming"] = False
                pass
            else:
                # Parse it, passing if it is gibberish
                try:

                    t, V1, V2, read_buffer[0] = parse_read2(raw)
                    # Update data dictionary
                    data["time_ms"] += t
                    data["Voltage"] += V1
                    data["Current"] += V2
                except:
                    pass

            # Sleep 80% of the time before we need to start reading chunks

        await asyncio.sleep(0.8 * n_reads_per_chunk * delay / 1000)


# Set up connection
HANDSHAKE = 0
START_PAUSE = 4
READ_SWEEPTIME = 5
READ_VLOW = 6
READ_VHIGH = 7
READ_NUM_SCAN = 8
STOP = 9

port = find_arduino()
arduino = serial.Serial(port, baudrate=115200)
handshake_arduino(arduino, print_handshake_message=True)

data = dict(
    prev_array_length=0, curr_streaming=False, time_ms=[], Voltage=[], Current=[]
)


def plot():
    """Build a plot of voltage vs current data"""
    # Set up plot area
    p = bokeh.plotting.figure(
        frame_width=500,
        frame_height=175,
        x_axis_label="voltage (V)",
        y_axis_label="current (mA)",
        title="Voltammogram",
        toolbar_location="above",
    )

    # We'll use whitesmoke backgrounds
    p.border_fill_color = "whitesmoke"

    # Define the data source
    source = bokeh.models.ColumnDataSource(
        data=dict(time_ms=[], Voltage=[], Current=[])
    )

    # Plot traces
    p.circle(source=source, x="Voltage", y="Current", visible=True, color="#f46d43")

    # Put a phantom circle so axis labels show before data arrive
    phantom_source = bokeh.models.ColumnDataSource(
        data=dict(time_ms=[0], Voltage=[0], Current=[0])
    )
    p.circle(source=phantom_source, x="Voltage", y="Current", visible=False)

    return p, source, phantom_source
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
